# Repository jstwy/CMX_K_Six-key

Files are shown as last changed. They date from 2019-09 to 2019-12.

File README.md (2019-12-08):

# CMX K Six-key
**Repository Organization**  
[`CMX_K_Six-Key.PCBDesignFiles`](https://github.com/jstwy/CMX_K_Six-key/tree/master/CMX_K_Six-Key.PCBDesignFiles) contains KiCAD files (schematic, PCB, and Gerber files)  
[`CMX_K_Six-Key.Firmware`](https://github.com/jstwy/CMX_K_Six-key/tree/master/CMX_K_Six-key.Firmware) contains firmware files (tmk_core submodule, configuration files, and compiled hex file)  
`CMX_K_Six-Key.Enclosure` contains enclosure design files (to be created...)

## PCB  
The design was done using KiCAD, following [ruiqimao's Keyboard PCB Guide](https://github.com/ruiqimao/keyboard-pcb-guide). The PCB was manufactured by [Oshpark](https://oshpark.com/) and hand-populated with components purchased from [Digi-Key Electronics](https://www.digikey.ca/), as listed in the [BOM](../master/CMX_K_Six-Key.BOM.csv).

## Firmware  
The keypad firmware was built using [tmk's TMK Keyboard Firmware Core Library](https://github.com/tmk/tmk_core), following [matt3o's keyboard firmware guide](https://deskthority.net/viewtopic.php?f=7&t=7177&start=). A virtual Linux Ubuntu machine was used to compile and flash the code.

Although the datasheet for the microcontroller indicates that the part used in this project, the ATMEGA32U4RC-AU, comes with a USB bootloader pre-programmed (see page 422 of the [datasheet](http://ww1.microchip.com/downloads/en/DeviceDoc/Atmel-7766-8-bit-AVR-ATmega16U4-32U4_Datasheet.pdf)), my microcontroller did not come with one. For that reason, I had to solder wires onto the SPI signal pins and the reset pin in order to program the microcontroller with an Arduino UNO [set up as an in-system programmer](https://www.arduino.cc/en/tutorial/arduinoISP).

The AVRDUDE command to program the fuses is:  
`avrdude -p m32u4 -P COM8 -c avrisp -b 19200 -U lfuse:w:0xff:m -U hfuse:w:0x98:m -U efuse:w:0xf7:m`  
where `COM8` is the COM port that my Arduino UNO was connected to.

The AVRDUDE command to flash the firmware is:  
`avrdude -p m32u4 -P COM8 -c avrisp -b 19200 -U flash:w:ATMega32U4-usbdevice_dfu-1_0_0.hex`  
where `ATMega32U4-usbdevice_dfu-1_0_0.hex` is the name of my hex file.

## Enclosure  
This part of the project has not been completed yet.

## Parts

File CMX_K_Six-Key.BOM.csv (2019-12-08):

Manufacturer Part Number | Manufacturer | Digi-Key Part Number | Customer Reference | Quantity | Unit Price | Extended Price | Description
ATMEGA32U4RC-AU | Microchip Technology | ATMEGA32U4RC-AU-ND | MCU - ATMEGA32U | 1 | 6.09000 | $6.09 | IC MCU 8BIT 32KB FLASH 44TQFP
FA-238 16.0000MB-C3 | EPSON | SER3686CT-ND | XTAL - EPSON FA-238 | 1 | 0.55000 | $0.55 | CRYSTAL 16.0000MHZ 18PF SMD
C0805C220J5GACTU | KEMET | 399-1113-1-ND | CAP - CER 0805 22 pF | 2 | 0.14000 | $0.28 | CAP CER 22PF 50V C0G/NP0 0805
CC0805ZRY5V9BB104 | Yageo | 311-1361-1-ND | CAP - CER 0805 0.1 uF | 4 | 0.14000 | $0.56 | CAP CER 0.1UF 50V Y5V 0805
CC0805KKX7R7BB105 | Yageo | 311-1365-1-ND | CAP - CER 0805 1uF | 1 | 0.24000 | $0.24 | CAP CER 1UF 16V X7R 0805
RMCF0805JT10K0 | Stackpole Electronics Inc | RMCF0805JT10K0CT-ND | RES - 0805 10 kOHM | 2 | 0.15000 | $0.30 | RES 10K OHM 5% 1/8W 0805
1N4148W-TP | Micro Commercial Co | 1N4148WTPMSCT-ND | DIODE - SOD-123 1.25 V @ 15 mA | 6 | 0.14000 | $0.84 | DIODE GEN PURP 100V 150MA SOD123
TL3342F160QG/TR | E-Switch | EG2531CT-ND | SWITCH - TACTILE 50 mA 12 V SPST | 1 | 0.99000 | $0.99 | SWITCH TACTILE SPST-NO 0.05A 12V
UX60SC-MB-5S8 | Hirose Electric Co Ltd | H11589CT-ND | CONN - R/A MINI B | 1 | 1.51000 | $1.51 | CONN RCPT USB2.0 MINI B SMD R/A
CL21A475KAQNNNE | Samsung Electro-Mechanics | 1276-1244-1-ND | CAP - CER 0805 4.7 uF | 1 | 0.26000 | $0.26 | CAP CER 4.7UF 25V X5R 0805
RMCF0805FT22R0 | Stackpole Electronics Inc | RMCF0805FT22R0CT-ND | RES - 0805 22 OHM | 2 | 0.15000 | $0.30 | RES 22 OHM 1% 1/8W 0805

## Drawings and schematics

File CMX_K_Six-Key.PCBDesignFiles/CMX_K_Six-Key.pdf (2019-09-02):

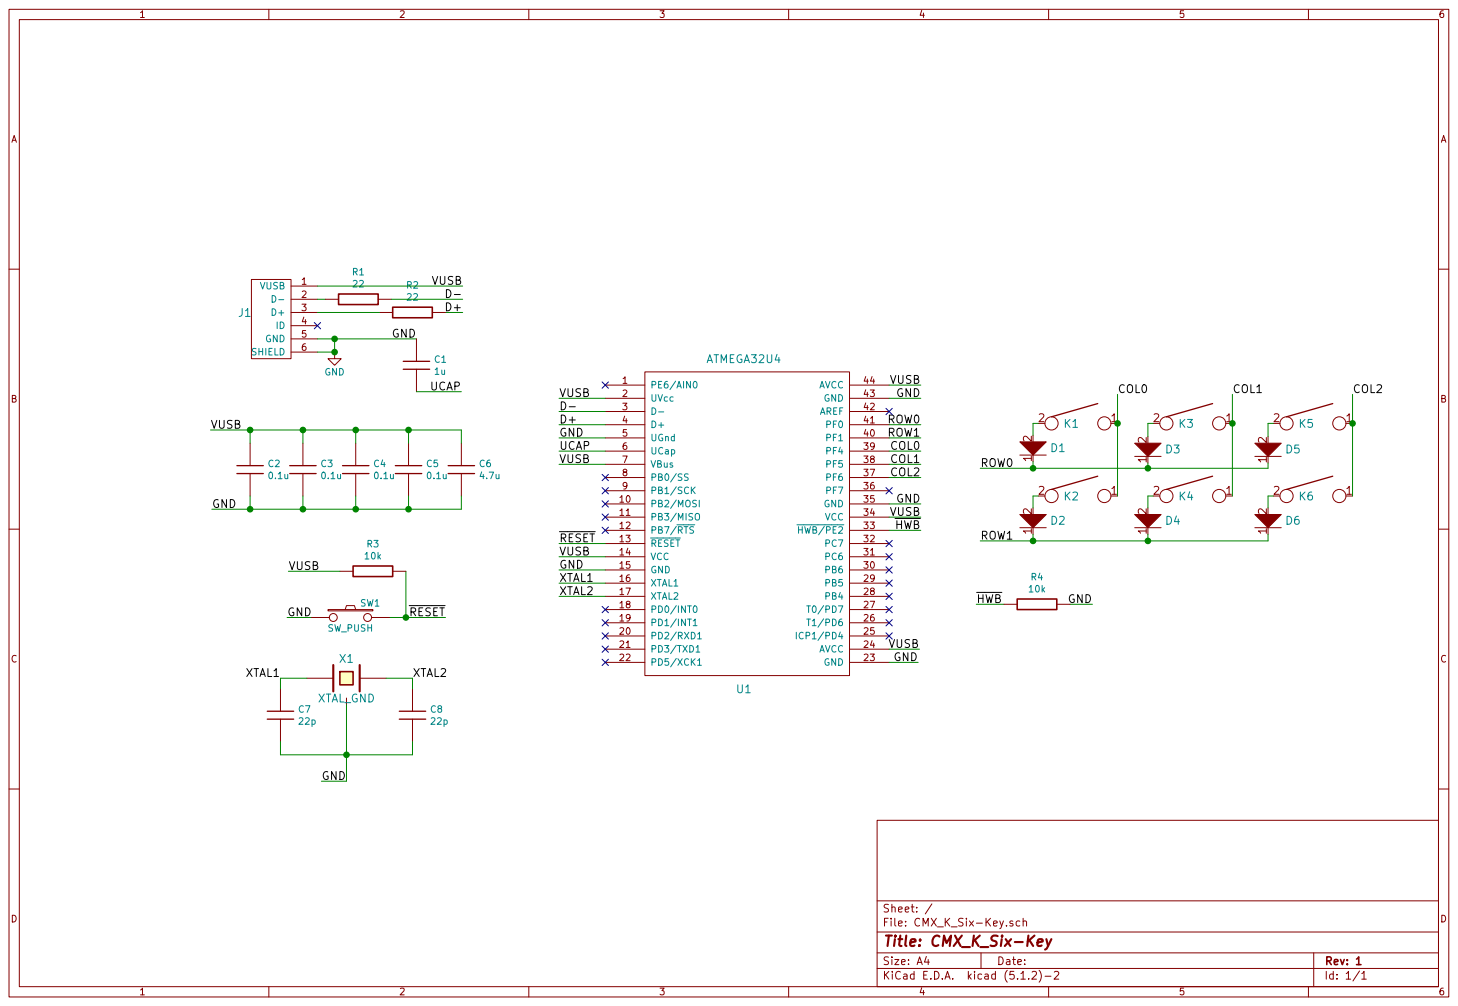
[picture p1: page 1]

File: CMX_K_Six-Key.sch Sheet: / XTAL1 XTAL2

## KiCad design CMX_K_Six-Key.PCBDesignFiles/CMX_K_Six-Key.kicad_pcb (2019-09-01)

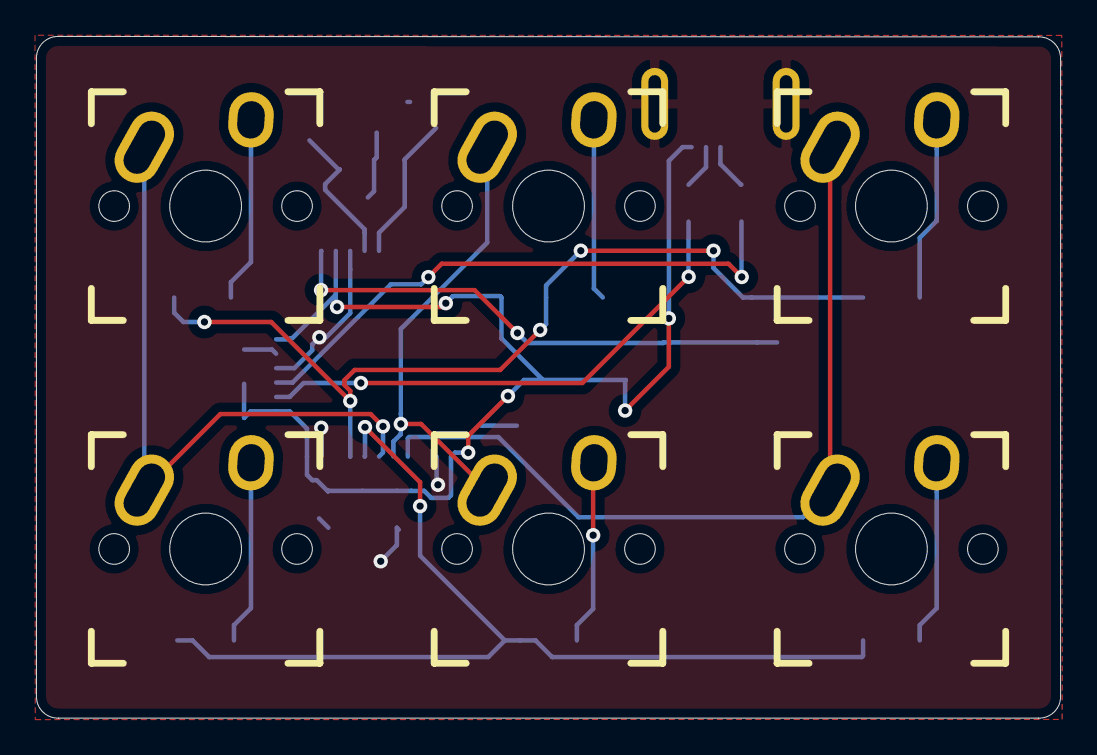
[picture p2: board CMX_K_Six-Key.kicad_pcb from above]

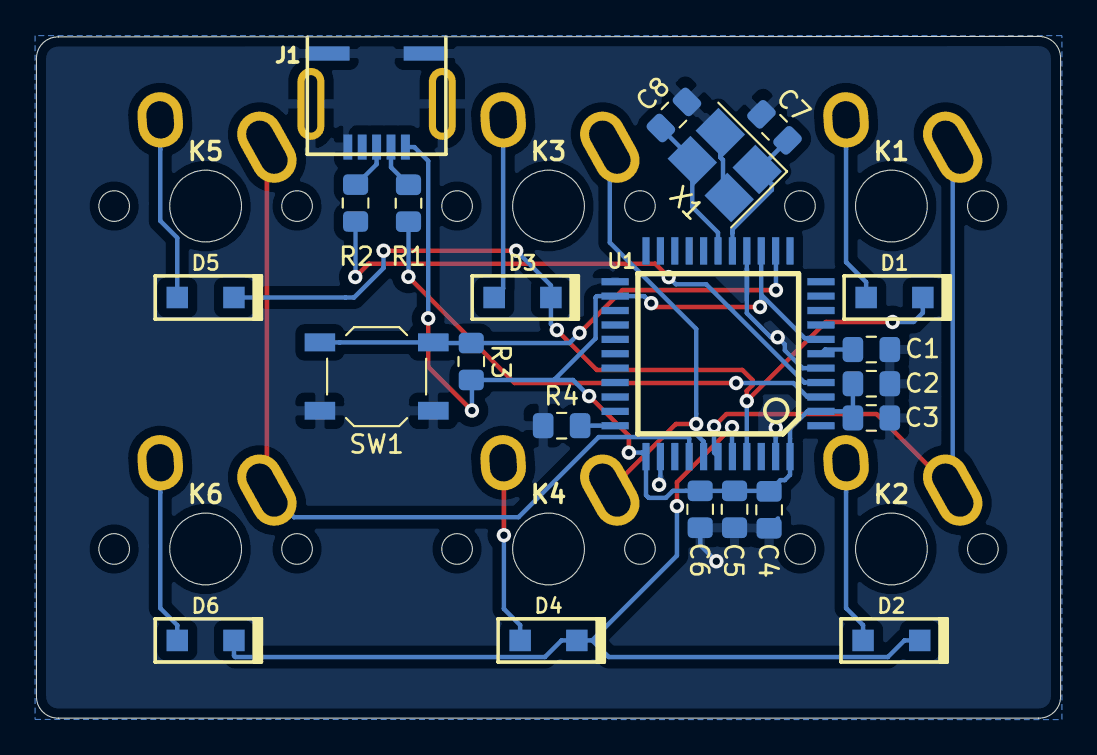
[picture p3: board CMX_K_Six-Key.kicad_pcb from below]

Board: 2 copper layers, 56.9 x 37.9 mm, 28 parts (22 on the bottom side), 22 nets.

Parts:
C1: 1u; C_0805_2012Metric_Pad1.15x1.40mm_HandSolder
C2, C3, C4, C5: 0.1u; C_0805_2012Metric_Pad1.15x1.40mm_HandSolder
C6: 4.7u; C_0805_2012Metric_Pad1.15x1.40mm_HandSolder
C7, C8: 22p; C_0805_2012Metric_Pad1.15x1.40mm_HandSolder
D1, D2, D3, D4, D5, D6: D; D_SOD123_hand
J1: USB_mini_micro_B; USB_miniB_hirose_5S8
K1, K2, K3, K4, K5, K6: KEYSW; Mx_Alps_100
R1, R2: 22; R_0805_2012Metric_Pad1.15x1.40mm_HandSolder
R3, R4: 10k; R_0805_2012Metric_Pad1.15x1.40mm_HandSolder
SW1: SW_PUSH; SW_SPST_TL3342
U1: ATMEGA32U4; QFP44
X1: XTAL_GND; Crystal_SMD_SeikoEpson_FA238-4Pin_3.2x2.5mm_HandSoldering

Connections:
/COL0: K1.1, K2.1, U1.39
/COL1: K3.1, K4.1, U1.38
/COL2: K5.1, K6.1, U1.37
/D+: R2.1, U1.4
/D-: R1.1, U1.3
/ROW0: D1.1, D3.1, D5.1, U1.41
/ROW1: D2.1, D4.1, D6.1, U1.40
/UCAP: C1.2, U1.6
/VUSB: C2.1, C3.1, C4.1, C5.1, C6.1, J1.1, R3.2, U1.2, U1.7, U1.14, U1.24, U1.34, U1.44
/XTAL1: C7.1, U1.16, X1.1
/XTAL2: C8.1, U1.17, X1.3
/~HWB~: R4.2, U1.33
/~RESET~: R3.1, SW1.2, U1.13
GND: C1.1, C2.2, C3.2, C4.2, C5.2, C6.2, C7.2, C8.2, J1.5, J1.6, R4.1, SW1.1, U1.5, U1.15, U1.23, U1.35, U1.43, X1.2, X1.4
unnamed: D1.2, K1.2
unnamed: D2.2, K2.2
unnamed: D3.2, K3.2
unnamed: D4.2, K4.2
unnamed: D5.2, K5.2
unnamed: D6.2, K6.2
unnamed: J1.2, R1.2
unnamed: J1.3, R2.2

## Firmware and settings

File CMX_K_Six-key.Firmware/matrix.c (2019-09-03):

/*
 * Original firmware files: Copyright 2012 Jun Wako <wakojun@gmail.com>, <github.com/tmk/tmk_keyboard>
 */

#include <stdint.h>
#include <stdbool.h>
#include <avr/io.h>
#include <util/delay.h>
#include "print.h"
#include "debug.h"
#include "util.h"
#include "matrix.h"


/*
 * CMX K Six-key
 *
 * Pin usage:
 *   COL: PF4-6
 *   ROW: PF0-1
 */
#ifndef DEBOUNCE
#   define DEBOUNCE	5
#endif
static uint8_t debouncing = DEBOUNCE;

/* Matrix state(1:on, 0:off) */
static matrix_row_t matrix[MATRIX_ROWS];
static matrix_row_t matrix_debouncing[MATRIX_ROWS];

static matrix_row_t read_cols(void);
static void init_cols(void);
static void unselect_rows(void);
static void select_row(uint8_t row);


void matrix_init(void)
{
    // JTAG disable for PORT F (write JTD bit twice within four cycles)
    MCUCR |= (1<<JTD);
    MCUCR |= (1<<JTD);

    // Initialize rows and cols
    unselect_rows();
    init_cols();

    // Initialize matrix state: all keys off
    for (uint8_t i=0; i < MATRIX_ROWS; i++) {
        matrix[i] = 0;
        matrix_debouncing[i] = 0;
    }
}

uint8_t matrix_scan(void)
{
    for (uint8_t i = 0; i < MATRIX_ROWS; i++) {
        select_row(i);
        _delay_us(30);  // Unstable value read without this delay
        matrix_row_t cols = read_cols();
        if (matrix_debouncing[i] != cols) {
            matrix_debouncing[i] = cols;
            if (debouncing) {
                debug("bounce!: "); debug_hex(debouncing); debug("\n");
            }
            debouncing = DEBOUNCE;
        }
        unselect_rows();
    }

    if (debouncing) {
        if (--debouncing) {
            _delay_ms(1);
        } else {
            for (uint8_t i = 0; i < MATRIX_ROWS; i++) {
                matrix[i] = matrix_debouncing[i];
            }
        }
    }

    return 1;
}

inline
matrix_row_t matrix_get_row(uint8_t row)
{
    return matrix[row];
}

/* Column pin configuration
 * col: 0   1   2
 * pin: F4  F5  F6
 */
static void  init_cols(void)
{
    DDRF  &= ~(1<<6 | 1<<5 | 1<<4);
    PORTF |=  (1<<6 | 1<<5 | 1<<4);
}

static matrix_row_t read_cols(void)
{
    return (PINF&(1<<4) ? 0 : (1<<0)) |
           (PINF&(1<<5) ? 0 : (1<<1)) |
           (PINF&(1<<6) ? 0 : (1<<2));
}

/* Row pin configuration
 * row: 0   1
 * pin: F0  F1
 */
static void unselect_rows(void)
{
    // Hi-Z(DDR:0, PORT:0) to unselect
    DDRF  &= ~0b00000011;
    PORTF &= ~0b00000011;
}

static void select_row(uint8_t row)
{
    // Output low(DDR:1, PORT:0) to select
    switch (row) {
        case 0:
            DDRF  |= (1<<0);
            PORTD &= ~(1<<0);
            break;
        case 1:
            DDRF  |= (1<<1);
            PORTD &= ~(1<<1);
            break;
    }
}

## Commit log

2019-09-01 Upload directory - PCB design files
    [CMX_K_Six-Key.kicad_pcb, CMX_K_Six-Key.sch]
2019-09-02 Upload file - PDF of schematic
2019-12-08 uploaded BOM
    [CMX_K_Six-Key.BOM.csv]
